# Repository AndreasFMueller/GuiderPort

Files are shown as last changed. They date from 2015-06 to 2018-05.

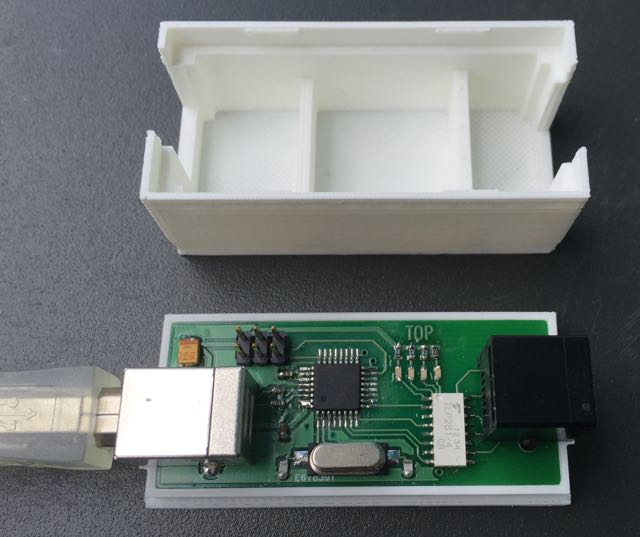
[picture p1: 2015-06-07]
GuiderPort.jpg

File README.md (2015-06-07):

GuiderPort

Most cameras for astrophotography have a guider port for autoguiding.
However, this is a really bad arrangment, because it requires an
additional cable between the telescope and the mount, adding an
additional force that could contribute to telescope flex. This
project offers the hardware and software for a standalone guider
port attached to a host computer via USB. This eliminates the need
for a guider port on the camera, and the guider port ist now directly
connected to the guiding computer.

The hardware uses an USB enable AVR microcontroller AT90USB162, but
an AT90USB82 is also sufficient. The schematics and board files in
KiCAD format are contained in the firmware directory. A suitable
case for the guider port hardware can be 3D-printed from the files
in the case subdirectory.

The firmware is based on the LUFA library. avr-gcc and avr-libc are
also needed to compile it. The Makefile contains targets to program
it using the avrispmk2 programmer and avrdude.

The client directory contains a libusb based client to test the
device.

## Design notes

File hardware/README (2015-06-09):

This directory contains the schematic and the board layout for the 
GuiderPort device created with KiCAD.

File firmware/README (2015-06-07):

This directory contains the firmware for the guider port device.

Instructions for building and installing the firmware can be found
in the file INSTALL.

What to expect from the device

The GuiderPort device has four opto-controller outputs. The state of
these outputs is also displayed on four LEDs mounted on the board.
The outputs are numbered 0 to 3, and are connected to the following
signals on the guider port:

	output		guider port signal
	------		------------------
	0		RAPLUS
	1		DECPLUS
	2		DECMINUS
	3		RAMINUS

The device is bus powered. When it is plugged into the bus it starts
up and indicates that it is ready by lighting the LEDs in a circular
pattern for about two seconds. Then the LEDs are turned off and the
device becomes visible on the USB bus.

The device has only a control endpoint. In addition to the commands
required by the USB standard, the device implements four vendor specific
commands. They should be sent as vendor specific device requests from
the host to the device. The parameters are specified in the wIndex and
wValue fields of the USB request,

RESET, bRequest = 0
	This command resets the microcontroller of the GuiderPort device.
	It disappears from the USB bus, goes through the initialization
	(flashing the LEDs as explained above) and reconnects to the bus.

SET, bRequest = 1
	This command allows to change the output state of some of the four 
	outputs. The low four bits of the wIndex field contain a bitmap
	indicating which outputs should be modified by the command, and
	the low four bits of the wValue field contain the new values for
	those bits.

SET_PORT_TIME, bRequest = 2
	This command sets the time in 100ths of a second during which
	the output specified by number in wIndex should be turned on.
	The time is specified in the wValue field of the request. The
	maximum value is 65535, which corresponds the 655.35 seconds.
	If the time specified in a previous request has not expired yet,
	then the command just resets the timer.

SET_ALL_TIMES, bRequest = 3
	This command allows to set the time for all outputs in a single
	request. Since the time values are 16 bit unsigned integers,
	the standard request structure does not allow for enough data.
	Thus the time values are sent as 8 bytes containing the for
	unsigned short numbers in little endian format. The values in
	wIndex and wValue are ignored.

GET, bRequest = 4
	This command retrieves the current state of the output as a
	bitmask.

Note that some mounts cannot handle multiple guider port outputs being
active at the same time. It is the responsibility of the driver software
to ensure that this does not happen for such mounts.

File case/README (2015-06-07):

This directory contains files to print a case for the GuiderPort
hardware. The OpenSCAD file case.scad contains the definition, the
STL file can be used for printing with most 3D-printers.

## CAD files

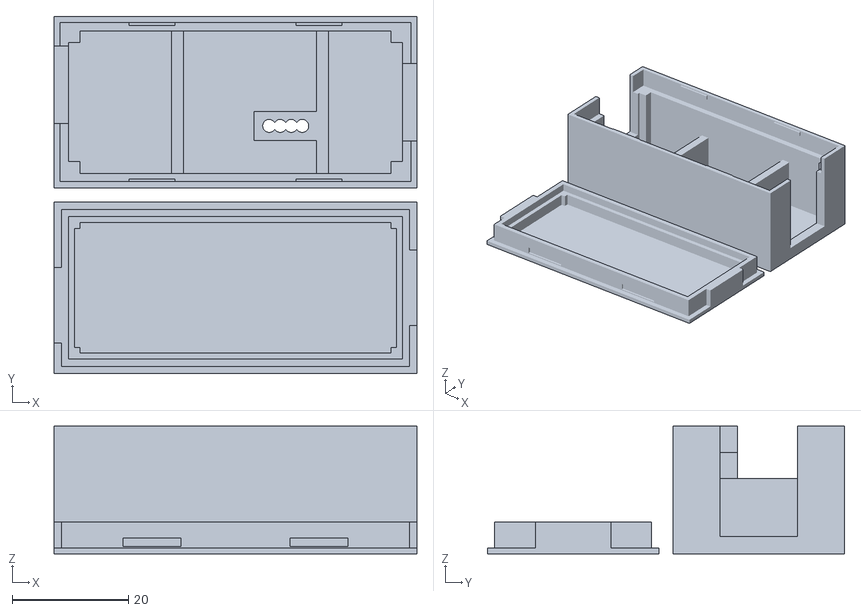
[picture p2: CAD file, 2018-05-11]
case/case.stl
62.5 x 61.5 x 22.0

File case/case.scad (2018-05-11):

/*
 * case.scad -- case for the guiderport hardware
 *
 * (c) 2015 Prof Dr Andreas Mueller, Hochschule Rapperswil
 */

// dimensions of the board
l = 57.15 + 0.4;
w = 24.13 + 0.4;
h = 22; // height of the top part of the case
wall = 2.5;

// dimensions of the box
L = l + 2 * wall;
W = w + 2 * wall;
H = 5;
s = 4.5;
board = 1.8; // board thickness
gap = 0.2;

// Bottom part
module	bottom() {
	difference() {
		union() {
			// floor piece
			translate([0, 0, 0.5])
				cube([L, W, 1], center = true);
			
			translate([0, 0, (s + 1) / 2])
				cube([L - wall, W - wall, s + 1], center = true);
		}
		union() { 
			// opening to accept the board
			translate([0, 0, (s + 1) / 2 + 1 + s - board])
				cube([l, w, s + 1], center = true);
			// the next two openings create a rest for the board
			translate([0, 0, (s + 1) / 2 + 1])
				cube([l - 2, w - 4, s + 1], center = true);
			translate([0, 0, (s + 1) / 2 + 1])
				cube([l - 4, w - 2, s + 1], center = true);

			// openings for latches
			translate([-l / 4, -(w + wall)/2, 2])
				cube([10, 1, 1.5], center = true); 
			translate([+l / 4, -(w + wall)/2, 2])
				cube([10, 1, 1.5], center = true); 
			translate([-l / 4, (w + wall)/2, 2])
				cube([10, 1, 1.5], center = true); 
			translate([+l / 4, (w + wall)/2, 2])
				cube([10, 1, 1.5], center = true);
		}
	}
    // for USB
	translate([-l / 2 - wall / 2, -3, (s + 1) / 2])
		cube([wall, 13, s + 1], center = true);
   // for autoguide jack
	translate([l / 2 + wall / 2, 0, (s + 1) / 2])
		cube([wall, 13, s + 1], center = true);
}

module	top() {
	difference() {
		union() {
			translate([0, 0, h / 2])
				cube([L, W, h], center = true);
		}
		union() {
			// opening ith rest for the board
			translate([0, 0, h / 2 - 1])
				cube([l, w - 4, h], center = true);
			translate([0, 0, h / 2 - 1])
				cube([l - 4, w, h], center = true);

			// opening for the bottom part to enter
			translate([0, 0, -5 + s])
				cube([L - wall + 2 * gap, W - wall + 2 * gap, 10], center = true);

			// opening for USB
			translate([-L / 2, -3, 5])
				cube([10, 13.4, 18 + 4], center = true);
			// opening for autoguide jack
			translate([L / 2, 0, 7])
				cube([10, 13.4, 20 + 4], center = true);
		}
	}

	// latches
	translate([-l / 4, -(w + wall)/2 - gap, 0.75])
		cube([8, 1, 1], center = true); 
	translate([+l / 4, -(w + wall)/2 - gap, 0.75])
		cube([8, 1, 1], center = true); 
	translate([-l / 4, (w + wall)/2 + gap, 0.75])
		cube([8, 1, 1], center = true); 
	translate([+l / 4, (w + wall)/2 + gap, 0.75])
		cube([8, 1, 1], center = true);

	// reinforcement bars in ceiling
	translate([-10, 0, h - 5.5])
		cube([2, W, 11], center = true);	
	translate([15, 0, h - 6.5])
		cube([2, W, 13], center = true);

	// holder for 
	translate([5.8 + 1.5 * 1.9, 4.1, h - 6.5])
		cube([11, 5, 13], center = true);
}

filamentdiameter = 1.75 + 0.5;

translate([0, 32, h])
	rotate([180, 0, 0])
		difference () {
			top();
			union() {
				translate([5.8 + 0 * 1.9, 4.1, h - 10])
					cylinder(h = 20, r = filamentdiameter / 2, center = true, $fn = 20);
				translate([5.8 + 1 * 1.9, 4.1, h - 10])
					cylinder(h = 20, r = filamentdiameter / 2, center = true, $fn = 20);
				translate([5.8 + 2 * 1.9, 4.1, h - 10])
					cylinder(h = 20, r = filamentdiameter / 2, center = true, $fn = 20);
				translate([5.8 + 3 * 1.9, 4.1, h - 10])
					cylinder(h = 20, r = filamentdiameter / 2, center = true, $fn = 20);
			}
		}

bottom();

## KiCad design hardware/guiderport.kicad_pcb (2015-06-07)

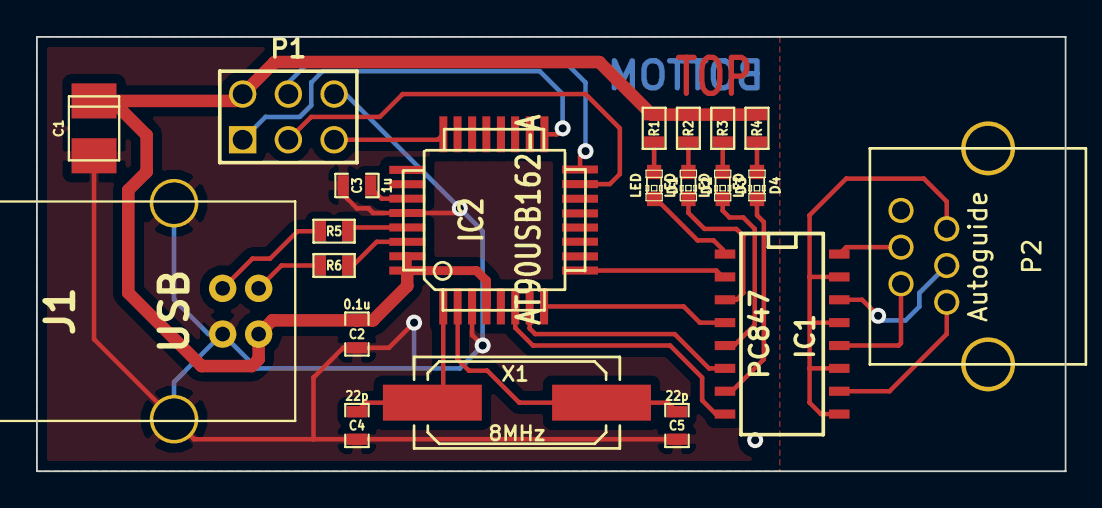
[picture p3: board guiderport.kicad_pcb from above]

Board: 2 copper layers, 57.1 x 24.1 mm, 21 parts (0 on the bottom side), 30 nets.

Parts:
C1: 10u; c_tant_B
C2: 0.1u; SM0603_Capa
C3: 1u; SM0603_Capa
C4, C5: 22p; SM0603_Capa
D1, D2, D3, D4: LED; LED-0603
IC1: PC847; SO16N
IC2: AT90USB162-A; TQFP32
J1: USB; USB_B
P1: ISP; pin_array_3x2
P2: Autoguide; Guiderport
R1, R2, R3, R4: 390; SM0603
R5, R6: 22; SM0603
X1: 8MHz; Q_49U3HMS

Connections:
+5V: C1.1, C2.1, IC2.4, IC2.31, IC2.32, J1.1, P1.2, R1.1, R2.1, R3.1, R4.1
GND: C1.2, C2.2, C3.2, C4.2, C5.2, IC2.3, IC2.28, J1.4, J1.5, J1.6, P1.6
unnamed: C3.1, IC2.27
unnamed: IC2.29, R5.1
unnamed: J1.3, R5.2
unnamed: IC2.30, R6.1
unnamed: J1.2, R6.2
unnamed: IC1.8, IC2.6
unnamed: IC2.15, P1.3
unnamed: IC2.16, P1.4
unnamed: IC2.24, P1.5
unnamed: IC1.6, IC2.7
unnamed: IC1.4, IC2.8
unnamed: IC1.2, IC2.9
unnamed: C4.1, IC2.1, X1.1
unnamed: C5.1, IC2.2, X1.2
unnamed: IC2.17, P1.1
unnamed: D2.2, IC1.3
unnamed: D4.1, R4.2
unnamed: D4.2, IC1.7
unnamed: IC1.9, IC1.11, IC1.13, IC1.15, P2.2
unnamed: IC1.10, P2.6
unnamed: D3.2, IC1.5
unnamed: IC1.14, P2.4
unnamed: D1.2, IC1.1
unnamed: IC1.16, P2.3
unnamed: D1.1, R1.2
unnamed: D2.1, R2.2
unnamed: D3.1, R3.2
unnamed: IC1.12, P2.5

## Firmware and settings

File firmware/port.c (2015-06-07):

/*
 * port.c -- implementation of the port interface
 *
 * (c) 2015 Prof Dr Andreas Mueller, Hochschule Rapperswil
 */
#ifdef HAVE_CONFIG_H
#include <config.h>
#endif /* HAVE_CONFIG_H */
#include <avr/io.h>
#include <util/atomic.h>
#include <port.h>


void	port_setup(void) __attribute__ ((constructor));

static porttimes_t	ports;

#define	PORT_ON(p)	do { PORTD &= ~(1 << p); } while (0)
#define	PORT_OFF(p)	do { PORTD |= (1 << p); } while (0)
#define PORT_GET(p)	((PORTD & (1 << p)) ? 0 : 1)

/**
 * \brief Turn port on
 *
 * Turn on the port indicated by the port number in argument port
 *
 * \param port	number of the port 0-3
 */
void	port_on(unsigned char port) {
	PORT_ON(port);
}

/**
 * \brief Turn port off
 *
 * Turn off the port indicated by the port number in argument port
 *
 * \param port	number of the port 0-3
 */
void	port_off(unsigned char port) {
	PORT_OFF(port);
}

/**
 * \brief Set the value of a port
 *
 * Set an output to a given value. If value is zero, then the port is
 * turned off, if it is nonzero, it is turned on.
 *
 * \param port		port number
 * \param value		whether the port should be on or off
 */
void	port_value(unsigned char port, unsigned char value) {
	if (value) {
		PORT_ON(port);
	} else {
		PORT_OFF(port);
	}
}

/**
 * \brief Get the state of a port
 *
 * Read the state of the output with number port
 *
 * \param port	number of the port 0-3
 */
unsigned char	port_get(unsigned char port) {
	return PORT_GET(port);
}

/**
 * \brief Retrieve all port values
 *
 * This function reads the current state of all ports and collects it in
 * a single unsigned char.
 */
unsigned char	port_get_all() {
	unsigned char	result = 0;
	for (unsigned char port = 0; port < 4; port++) {
		result |= port_get(port) ? (1 << port) : 0;
	}
	return result;
}

/**
 * \brief Port setup
 *
 * This function configures the IO-pins D0-D3 as outputs and turns them off.
 * This method has the constructor attribute, which ensures that it is
 * called automatically during startup.
 */
void	port_setup(void) {
	// initialize ports
	PORTD |= (1 << PORTD0) | (1 << PORTD1) | (1 << PORTD2) | (1 << PORTD3);
	DDRD  |= (1 << DDD0)   | (1 << DDD1)   | (1 << DDD2)   | (1 << DDD3);

	// turn of outputs and reset timers
	for (unsigned char i = 0; i < 4; i++) {
		port_value(i, 0);
		ports[i] = 0;
	}
}

/**
 * \brief Set time value for a port
 *
 * This function sets/overwrites the time during which the port selected
 * by the port argument should be turned on. 
 *
 * \param port		port number 0-3
 * \param value		time in 10ms intervals
 */
void	port_set(unsigned char i, unsigned short value) {
	ATOMIC_BLOCK(ATOMIC_RESTORESTATE) {
		if (0 == value) {
			if (0 != ports[i]) {
				port_off(i);
			}
			ports[i] = 0;
		} else {
			if (0 == ports[i]) {
				port_on(i);
			}
			ports[i] = value;
		}
	}
}

/**
 * \brief Set all port times
 *
 * This function sets the port time for all ports. It is used by the
 * implementation of the SET_ALL_TIMES request.
 *
 * \param p	array containing on times for all ports
 */
void	port_set_all(const porttimes_t p) {
	for (unsigned char i = 0; i < 4; i++) {
		port_set(i, p[i]);
	}
}

/**
 * \brief Perform a timer step 
 *
 * This function is called from the timer interrupt to count down the 
 * timer values of the ports.
 */
void	port_step(unsigned short delta) {
	// check whether to turn off the raplus port
	for (unsigned char i = 0; i < 4; i++) {
		ATOMIC_BLOCK(ATOMIC_RESTORESTATE) {
			if (ports[i] > delta) {
				ports[i] -= delta;
			} else {
				if (0 != ports[i]) {
					port_off(i);
				}
				ports[i] = 0;
			}
		}
	}
}

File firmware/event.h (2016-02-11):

/*
 * event.h -- function to handle USB events
 *
 * (c) 2015 Prof Dr Andreas Mueller, Hochschule Rapperswil
 */
#ifndef _event_h
#define _event_h

#include <LUFA/Drivers/USB/USB.h>

/**
 * \brief Command codes for the GuiderPort commands
 *
 * A description of the commands is given in event.c where the
 * commands are implemented.
 */
#define	GUIDERPORT_RESET		0
#define	GUIDERPORT_SET			1
#define GUIDERPORT_SET_PORT_TIME	2
#define GUIDERPORT_SET_ALL_TIMES	3
#define GUIDERPORT_GET			4
#define GUIDERPORT_SERIAL		5

/**
 * \brief Event handle for control requests
 *
 * This function is called when a control request arrives at the device.
 * It implements the four commands understood by the device. Note that
 * this function must be linked, and sometimes the -u linker option is
 * needed to force the linker to do that.
 */
extern void	EVENT_USB_Device_ControlRequest();

#endif /* _event_h */

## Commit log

2015-06-07 initial release
    [case.scad, case.stl, guiderport.kicad_pcb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]
2015-06-07 add LED holes to case
    [case.scad, case.stl]
2015-06-08 improve gaps
    [case.scad, case.stl]
2016-02-10 fix typo
    [case.scad, case.stl]
2018-05-11 add missing serial.h
    [case.scad, case.stl]
